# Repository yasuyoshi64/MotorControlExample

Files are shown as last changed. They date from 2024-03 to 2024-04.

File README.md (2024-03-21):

# sdkconfig
Serial flasher config

	Flash size				4MB

Partition Table

	Patition Table			Single factory app (large), no OTA

MotorControlExample

	LED GPIO number			5

SD card PIN configuration

	MOSI GPIO number		17
	MOSO GPIO number		19
	CLK GPIO number			18
	CS GPIO number			16
	SD card sw GPIO number	4

OLED(SSD1306) PIN configuration

	I2C SDA GPIO number		21
	I2C SCL GPIO number		22

MOTOR(BD65496) PIN configuration

	INA GPIO NUMBER			12
	INB GPIO NUMBER			13

HTTP Server

	WebSocket server support	TRUE

FAT Filesystem support

	Long filename support	Long filename buffer in heap
	OEM Code Page			Japanese (DBCS) (CP932)

Color settings

	Color depth.			1: 1 byte per pixel

Font usage

Enable built-in fonts

	Enable UNSCII 8 (Perfect monospace font)	TRUE

3rd Party Libraries

	QR code library			TRUE

# 機能

## SDカードの内容

### ./config

```
ssid=[Wi-Fi SSID]
pass=[Wi-Fi Password]
```

### ./document

ここにはWeb用のファイルを格納します。

## 使い方

* 「No file」と表示されている場合はSDカードを挿入します。
* 「Wi-Fi Connecting」はWi-Fi接続中です。
* Wi-Fi接続完了後はQRコードが表示されます。QRコードを読み込むとWebのURLが読み込まれ、documentのWebが表示されます。
* QRコードは30秒で消灯します。GPIO0のボタンを押下すると再度30秒表示されます。
* SDカードは電源ON中でも抜き差し可能です。

FA-130モーターは無負荷で70%くらいから回転を始めます。一度回転を始めれば40%くらいまで落としても回転します。
60% = 9000RPM ～　100% = 19000RPM

## 回路図

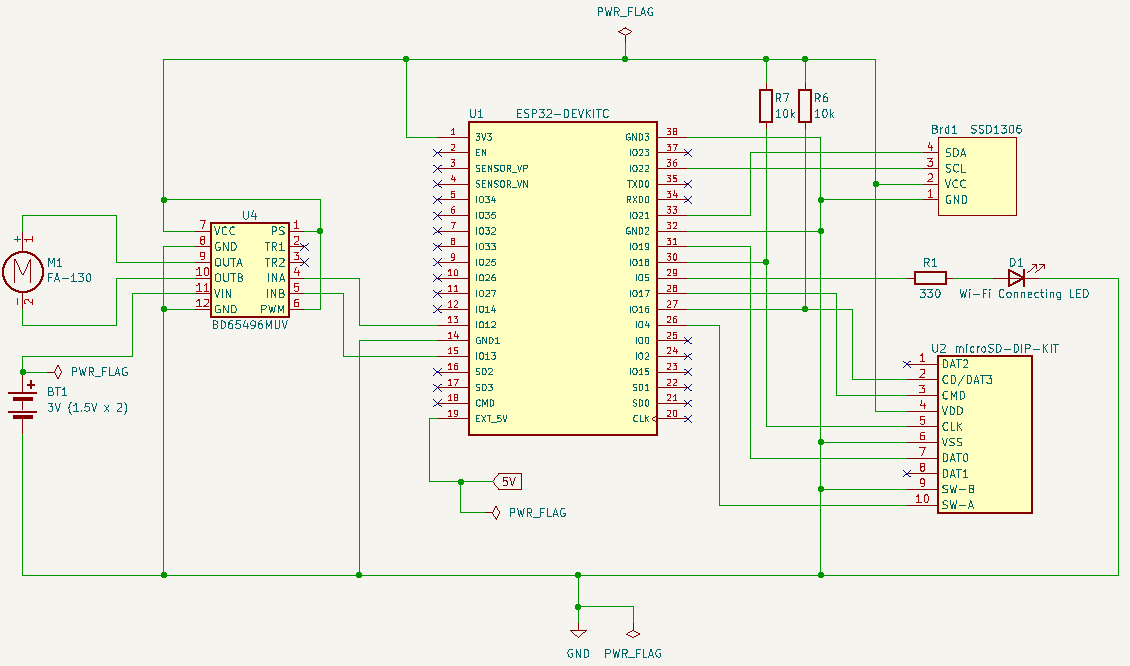
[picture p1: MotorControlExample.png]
回路図


## Web画面

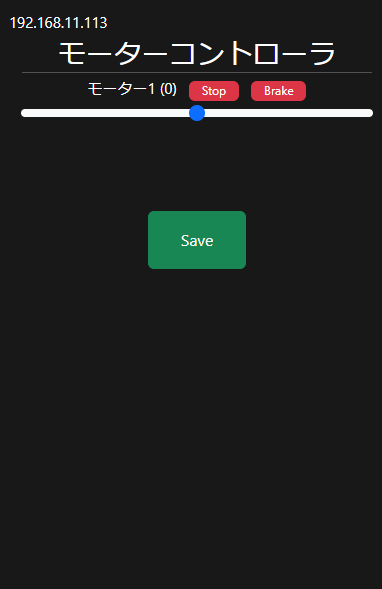
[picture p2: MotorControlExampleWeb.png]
Web画面


スライダーを動かすことでモーターを操作できます。
Saveボタンは何も機能しません。

# _Sample project_

(See the README.md file in the upper level 'examples' directory for more information about examples.)

This is the simplest buildable example. The example is used by command `idf.py create-project`
that copies the project to user specified path and set it's name. For more information follow the [docs page](https://docs.espressif.com/projects/esp-idf/en/latest/api-guides/build-system.html#start-a-new-project)

## How to use example
We encourage the users to use the example as a template for the new projects.
A recommended way is to follow the instructions on a [docs page](https://docs.espressif.com/projects/esp-idf/en/latest/api-guides/build-system.html#start-a-new-project).

## Example folder contents

The project **sample_project** contains one source file in C language [main.c](main/main.c). The file is located in folder [main](main).

ESP-IDF projects are built using CMake. The project build configuration is contained in `CMakeLists.txt`
files that provide set of directives and instructions describing the project's source files and targets
(executable, library, or both). 

Below is short explanation of remaining files in the project folder.

```
├── CMakeLists.txt
├── main
│   ├── CMakeLists.txt
│   └── main.c
└── README.md                  This is the file you are currently reading
```
Additionally, the sample project contains Makefile and component.mk files, used for the legacy Make based build system. 
They are not used or needed when building with CMake and idf.py.

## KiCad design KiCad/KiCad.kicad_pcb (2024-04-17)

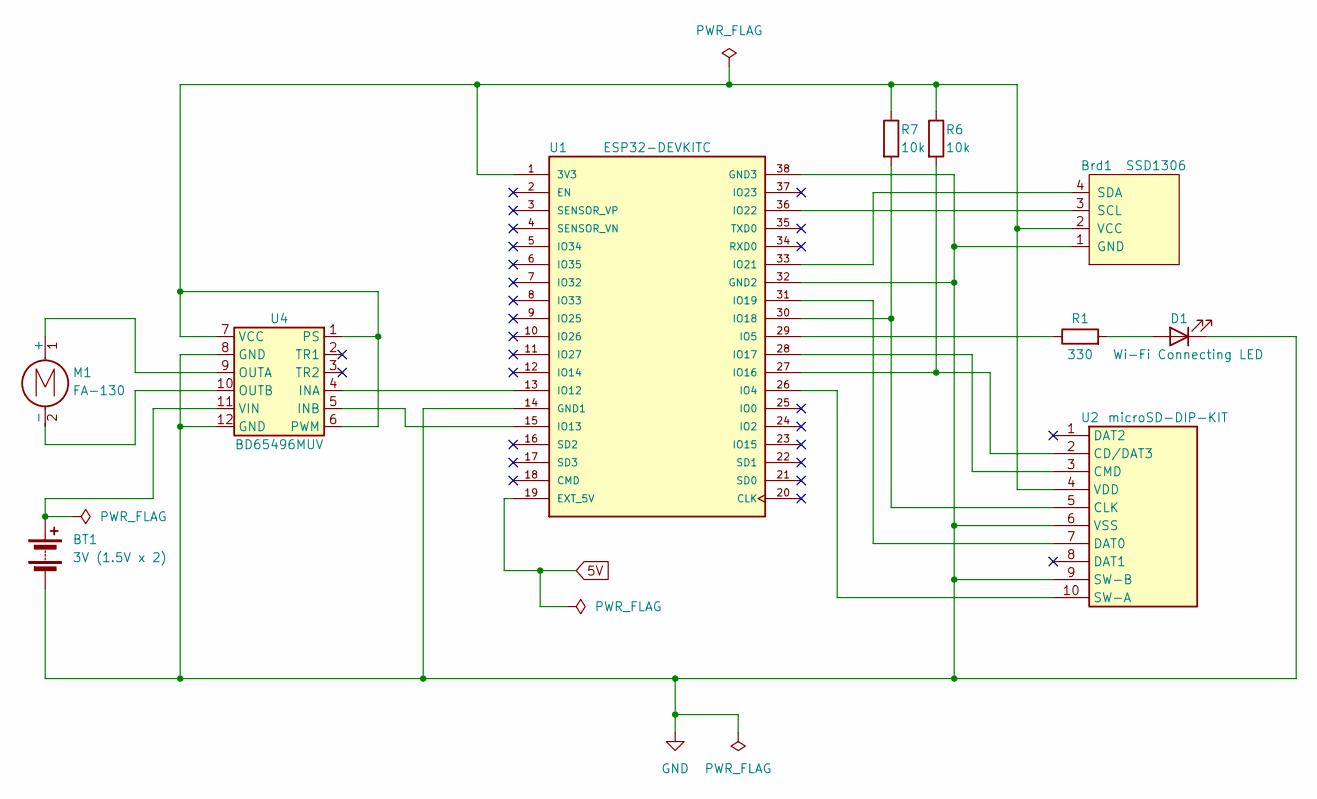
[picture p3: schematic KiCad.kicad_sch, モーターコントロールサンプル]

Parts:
BT1: 3V (1.5V x 2); PinHeader_1x02_P1.27mm_Vertical
Brd1: SSD1306; 128x64OLED
D1: Wi-Fi Connecting LED; LED_D5.0mm
M1: FA-130; PinHeader_1x02_P1.27mm_Vertical
R1: 330; R_Axial_DIN0204_L3.6mm_D1.6mm_P5.08mm_Horizontal
R6, R7: 10k; R_Axial_DIN0204_L3.6mm_D1.6mm_P5.08mm_Horizontal
U1: ESP32-DEVKITC; MODULE_ESP32-DEVKITC; PARTREV N/A
U2: microSD-DIP-KIT; microSD-DIP-Kit
U4: BD65496MUV

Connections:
5V: U1.19 (EXT_5V)
GND: BT1.2 (-), Brd1.1 (GND), D1.1 (K), U1.14 (GND1), U1.32 (GND2), U1.38 (GND3), U2.6 (VSS), U2.9 (SW-B), U4.8 (GND), U4.12 (GND)
unnamed: BT1.1 (+), U4.11 (VIN)
unnamed: Brd1.3 (SCL), U1.36 (IO22)
unnamed: Brd1.4 (SDA), U1.33 (IO21)
unnamed: Brd1.2 (VCC), R6.1, R7.1, U1.1 (3V3), U2.4 (VDD), U4.1 (PS), U4.6 (PWM), U4.7 (VCC)
unnamed: D1.2 (A), R1.2
unnamed: M1.1 (+), U4.9 (OUTA)
unnamed: M1.2 (-), U4.10 (OUTB)
unnamed: U1.26 (IO4), U2.10 (SW-A)
unnamed: R1.1, U1.29 (IO5)
unnamed: U1.13 (IO12), U4.4 (INA)
unnamed: U1.15 (IO13), U4.5 (INB)
unnamed: R6.2, U1.27 (IO16), U2.2 (CD/DAT3)
unnamed: U1.28 (IO17), U2.3 (CMD)
unnamed: R7.2, U1.30 (IO18), U2.5 (CLK)
unnamed: U1.31 (IO19), U2.7 (DAT0)

Board: 2 copper layers, 10 parts (0 on the bottom side), 16 nets, no tracks yet.

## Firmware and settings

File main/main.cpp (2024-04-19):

#include <stdio.h>
#include <sys/types.h>
#include <dirent.h>
#include <errno.h>
#include <string.h>
#include <iostream>
#include <map>
#include "freertos/FreeRTOS.h"
#include "freertos/task.h"
#include "freertos/queue.h"
#include "freertos/timers.h"
#include "nvs_flash.h"
#include "driver/gpio.h"
#include "esp_http_server.h"
#include "cJSON.h"
#include "esp_log.h"

#include "main.hpp"

#define TAG "Application"
#define ROOT "/mnt"

Application app;

// メッセージ種別 (メッセージキュー用)
enum class AppMessage {
    UpdateDisplay,      // ディスプレイに現在状態表示
    WIFIConnection,     // Wi-Fi接続
    WIFIDisconnection,  // Wi-Fi切断
    Quit                // 終了
};

Application::Application() {
    m_LedState = false;
    m_xHandle = NULL;
    m_xQueue = NULL;
    m_isWiFi = false;
    m_30sec_off = false;
}

// 初期化
void Application::init() {
    ESP_LOGI(TAG, "Init(S)");

    // LED初期化
    gpio_reset_pin((gpio_num_t)CONFIG_LED_PIN);
    gpio_set_direction((gpio_num_t)CONFIG_LED_PIN, GPIO_MODE_OUTPUT);
    led(0);

    // ボタン初期化(GPIO0)
    gpio_reset_pin((gpio_num_t)0);
    gpio_set_intr_type((gpio_num_t)0, GPIO_INTR_NEGEDGE);
    gpio_set_direction((gpio_num_t)0, GPIO_MODE_INPUT);
    gpio_pulldown_dis((gpio_num_t)0);
    gpio_pullup_en((gpio_num_t)0);
    gpio_install_isr_service(0);
    gpio_isr_handler_add((gpio_num_t)0, btn0HandlerFunc, (void*)this);

    // タスク作成
    xTaskCreate(Application::app_task, TAG, configMINIMAL_STACK_SIZE * 2, (void*)this, tskIDLE_PRIORITY, &m_xHandle);

    // メッセージキューの初期化
    m_xQueue = xQueueCreate(10, sizeof(AppMessage));

    // SDカード初期化
    m_sd_card.init(ROOT);
    m_sd_card.setMountCallback(mountFunc, this);

    // 保存データ初期化
    m_save_data.init(ROOT);

    // モーターコントローラー
    m_motor.init(0, (gpio_num_t)CONFIG_INA_PIN, (gpio_num_t)CONFIG_INB_PIN);

    // OLED(SSD1306)ディスプレイ初期化
    m_oled.init(dispInitCompFunc, this);

    // Wi-Fi初期化
    m_wifi.init(wifiConnectFunc, this);

    // Webサーバー初期化
    m_web.init();
    m_web.addHandler(HTTP_GET, "get_data", getData, this);
    m_web.addHandler(HTTP_POST, "set_data", setData, this);
    m_web.addHandler(HTTP_POST, "save", save, this);
    m_web.setWebSocketHandler(sebSocketFunc, this);

    ESP_LOGI(TAG, "Init(E)");
}

// タスク
void Application::app_task(void* arg) {
    Application* pThis = (Application*)arg;
    AppMessage msg;
    bool loop = true;
    while(loop) {
        // メッセージキュー読み取り
        if (pThis->m_xQueue != NULL && xQueueReceive(pThis->m_xQueue, (void*)&msg, portMAX_DELAY) == pdTRUE) {
            switch(msg) {
                case AppMessage::UpdateDisplay:     // ディスプレイに現在状態表示
                    pThis->updateDisplay();
                    break;
                case AppMessage::WIFIConnection:    // Wi-Fi接続
                    pThis->wifiConnection();
                    break;
                case AppMessage::WIFIDisconnection: // Wi-Fi切断
                    pThis->wifiDisconnection();
                    break;
                case AppMessage::Quit:              // 終了
                    loop = false;
                    break;
            }
        }
    }
    // 終了処理
    vTaskDelete(NULL);
}

// LED点灯制御
//  state   : 1=点灯, 0=消灯
void Application::led(int state) {
    m_LedState = state;
    gpio_set_level((gpio_num_t)CONFIG_LED_PIN, m_LedState);
}

// SDカードマウントコールバック
void Application::mountFunc(bool isMount, void* context) {
    ESP_LOGI(TAG, "SD Card mount : %d", isMount);
    Application* pThis = (Application*)context;
    AppMessage msg = AppMessage::UpdateDisplay;
    xQueueSend(pThis->m_xQueue, &msg, portMAX_DELAY);
    if (isMount && pThis->getConfig(ROOT)) {
        AppMessage msg = AppMessage::WIFIConnection;
        xQueueSend(pThis->m_xQueue, &msg, portMAX_DELAY);
    } else {
        AppMessage msg = AppMessage::WIFIDisconnection;
        xQueueSend(pThis->m_xQueue, &msg, portMAX_DELAY);
    }
    // 保存データ読み込み
    pThis->m_save_data.read();
}

// ファイル一覧コールバック
bool Application::fileFunc(bool isFile, const char* name, void* context) {
    ESP_LOGI(TAG, "%s : %s", isFile ? "File" : "Directory", name);
    return true;
}

// ディスプレイ初期化完了コールバック
void Application::dispInitCompFunc(void* context) {
    Application* pThis = (Application*)context;
    AppMessage msg = AppMessage::UpdateDisplay;
    xQueueSend(pThis->m_xQueue, &msg, portMAX_DELAY);
}

// Wi-Fi接続コールバック
void Application::wifiConnectFunc(bool isConnect, void* context) {
    Application* pThis = (Application*)context;
    if (isConnect) {
        pThis->m_30sec_off = pThis->m_isWiFi = true;
        const char* ipAddress = pThis->m_wifi.getIPAddress();
        ESP_LOGI(TAG, "IP Address: %s", ipAddress);
        pThis->led(0);
        pThis->m_web.start(ipAddress, ROOT);   // Webサーバー開始

        // 30秒後に画面を消灯するためにタイマ設定
        pThis->timer30secStart();

        // pThis->m_sd_card.fileLists("/document/", fileFunc, pThis);
    } else {
        ESP_LOGW(TAG, "wi-fi disconnect");
        pThis->m_30sec_off = pThis->m_isWiFi = false;
    }
    AppMessage msg = AppMessage::UpdateDisplay;
    xQueueSend(pThis->m_xQueue, &msg, portMAX_DELAY);
}

// 30秒タイマ開始
void Application::timer30secStart() {
    TimerHandle_t xTimer = xTimerCreate(
        "30SecTimer",
        pdMS_TO_TICKS(30000),
        pdFALSE,
        this,
        timer30secFunc
    );
    if (xTimer != NULL)
        xTimerStart(xTimer, 0);
}

// 30秒タイマ
void Application::timer30secFunc(TimerHandle_t xTimer) {
    Application* pThis = (Application*)pvTimerGetTimerID(xTimer);
    ESP_LOGI(TAG, "30s timer handler");
    pThis->m_30sec_off = false;
    AppMessage msg = AppMessage::UpdateDisplay;
    xQueueSend(pThis->m_xQueue, &msg, portMAX_DELAY);
}

// 基盤上のボタン押下ハンドラ (GPIO0)
void IRAM_ATTR Application::btn0HandlerFunc(void* context) {
    Application* pThis = (Application*)context;
    if (pThis->m_30sec_off == false) {
        pThis->m_30sec_off = true;
        pThis->timer30secStart();
        AppMessage msg = AppMessage::UpdateDisplay;
        xQueueSend(pThis->m_xQueue, &msg, portMAX_DELAY);
    }
}

// ディスプレイに現在状態表示
void Application::updateDisplay() {
    if (!m_oled.isInitialize())
        return;
    if (m_isWiFi) {
        if (m_30sec_off) {
            ESP_LOGI(TAG, "QRCode output");
            const char* ipAddress = m_wifi.getIPAddress();
            char url[256];
            sprintf(url, "http://%s/", ipAddress);
            m_oled.dispQRCode(url);
        } else {
            // 画面消灯
            m_oled.dispClear();
        }
    } else if (m_sd_card.isMount()) {
        m_oled.dispString("Wi-Fi Connecting");
        led(1);
    } else {
        m_oled.dispString("No File");
        led(0);
    }
}

// Wi-Fi接続
void Application::wifiConnection() {
    wifiDisconnection();
    if (m_configMap.find("ssid") == m_configMap.end() || m_configMap.find("pass") == m_configMap.end())
        return; // CONFIGファイルにssidまたはpassの設定がない
    const char* ssid = m_configMap["ssid"].c_str();
    const char* pass = m_configMap["pass"].c_str();
    m_wifi.connect(ssid, pass);
}

// Wi-Fi切断
void Application::wifiDisconnection() {
    m_web.stop();
    m_wifi.disconnect();
}

// WebAPI GET /API/get_data
// {
//   "ip_address": "192.168.0.1",
// }
void Application::getData(httpd_req_t *req, void* context) {
    ESP_LOGI(TAG, "getData");
    Application* pThis = (Application*)context;
    char resp[100];
    const char* ip_address = pThis->m_wifi.getIPAddress();
    ip_address = ip_address == NULL ? "" : ip_address;
    sprintf(resp, "{\"ip_address\": \"%s\" }", ip_address);
    ESP_LOGI(TAG, "%s", resp);
    httpd_resp_set_type(req, "application/json");
    httpd_resp_send(req, resp, strlen(resp));
}

// WebAPI POST /API/set_data
// {
//   "servo_trim": 5
// }
void Application::setData(httpd_req_t *req, void* context) {
    ESP_LOGI(TAG, "setData");
    Application* pThis = (Application*)context;
    int ret, remaining = req->content_len;
    char body[100];
    if (remaining >= sizeof(body)) {
        ESP_LOGE(TAG, "oversize request body");
        httpd_resp_send_500(req);
        return;
    }
    ret = httpd_req_recv(req, body, remaining);
    if (ret == HTTPD_SOCK_ERR_TIMEOUT) {
        ESP_LOGE(TAG, "timeout");
        httpd_resp_send_408(req);
        return;
    }
    body[ret] = '\0';
    ESP_LOGI(TAG, "body : %s", body);
    cJSON* json = cJSON_Parse(body);
    if (json == NULL) {
        ESP_LOGI(TAG, "json null");
        httpd_resp_send_500(req);
        return;
    }
    // cJSON* servo_trim = cJSON_GetObjectItemCaseSensitive(json, "servo_trim");
    // if (!cJSON_IsNumber(servo_trim)) {
    //     ESP_LOGI(TAG, "json format error");
    //     httpd_resp_send_500(req);
    //     return;
    // }
    // double trim = cJSON_GetNumberValue(servo_trim);
    // pThis->m_save_data.set("servo_trim", std::to_string(trim).c_str());
    cJSON_Delete(json);
    httpd_resp_send(req, NULL, 0);
}

// WebAPI POST /API/save
void Application::save(httpd_req_t *req, void* context) {
    ESP_LOGI(TAG, "save");
    Application* pThis = (Application*)context;
    pThis->m_save_data.save();
    httpd_resp_send(req, NULL, 0);
}

// WebSocketコールバック
char* Application::sebSocketFunc(const char* data, void* context) {
    Application* pThis = (Application*)context;
    ESP_LOGI(TAG, "data = %s", data);
    std::string str = data;
    int speed = 0;
    MotorDirection md = MotorDirection::Stop;
    if (str == "brake") {
        speed = 0;
        md = MotorDirection::Brake;
    } else {
        speed = std::stoi(str);
        if (speed == 0) {
            md = MotorDirection::Stop;
        } else if (speed > 0) {
            md = MotorDirection::Foward;
        } else if (speed < 0) {
            md = MotorDirection::Back;
            speed *= -1;
        }
    }
    pThis->m_motor.setDirection(md);
    pThis->m_motor.setSpeed(speed);
    return NULL;
}

extern "C" void app_main(void)
{
    nvs_flash_init();     // Flash初期化  (お約束のようなもの)

    app.init();
}

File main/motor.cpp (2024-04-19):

#include <cmath>
#include "motor.hpp"
#include "esp_log.h"

#define TAG "Motor"

#define MOTOR_PWM_RESOLUTION_HZ 1000000       // 1MHz, 1us per tick
#define MOTOR_PWM_PERIOD 100                // 100 tick, 100μs = 10kHzのPWM周期

// メッセージ種別 (メッセージキュー用)
enum class MotorMessage {
    Speed           // 速度
};

Motor::Motor() {
    clear();
}

void Motor::clear() {
    m_xHandle = NULL;
    m_xQueue = NULL;
    m_gpioINA = (gpio_num_t)0;
    m_gpioINB = (gpio_num_t)0;
    m_md = MotorDirection::Stop;
    m_timer = NULL;
    m_oper = NULL;
    m_comparator = NULL;
    m_generator = NULL;
    m_speed = 0;
}

void Motor::init(int groupID, gpio_num_t gpioINA, gpio_num_t gpioINB) {
    ESP_LOGI(TAG, "init(S)");

    m_groupID = groupID;
    m_gpioINA = gpioINA;
    m_gpioINB = gpioINB;

    // タスク作成
    xTaskCreate(Motor::task, TAG, configMINIMAL_STACK_SIZE * 2, (void*)this, 1, &m_xHandle);

    // メッセージキューの初期化
    m_xQueue = xQueueCreate(10, sizeof(MotorMessage));

    // PWM初期化
    ESP_LOGI(TAG, "init(1)");
    m_timer = NULL;
    mcpwm_timer_config_t timer_config = {
        .group_id = m_groupID,
        .clk_src = MCPWM_TIMER_CLK_SRC_DEFAULT,
        .resolution_hz = MOTOR_PWM_RESOLUTION_HZ,
        .count_mode = MCPWM_TIMER_COUNT_MODE_UP,
        .period_ticks = MOTOR_PWM_PERIOD,
    };
    esp_err_t ret = mcpwm_new_timer(&timer_config, &m_timer);
    if (ret != ESP_OK) {
        ESP_LOGE(TAG, "mcpwm_new_timer error %d", ret);
        return;
    }

    ESP_LOGI(TAG, "init(2)");
    m_oper = NULL;
    mcpwm_operator_config_t operator_config = {
        .group_id = m_groupID,
    };
    ret = mcpwm_new_operator(&operator_config, &m_oper);
    if (ret != ESP_OK) {
        ESP_LOGE(TAG, "mcpwm_new_operator error %d", ret);
        return;
    }
    ret = mcpwm_operator_connect_timer(m_oper, m_timer);
    if (ret != ESP_OK) {
        ESP_LOGE(TAG, "mcpwm_operator_connect_timer error %d", ret);
        return;
    }

    ESP_LOGI(TAG, "init(3)");
    m_comparator = NULL;
    mcpwm_comparator_config_t comparator_config {
        .flags = {
            .update_cmp_on_tez = true
        }
    };
    ret = mcpwm_new_comparator(m_oper, &comparator_config, &m_comparator);
    if (ret != ESP_OK) {
        ESP_LOGE(TAG, "mcpwm_new_comparator error %d", ret);
        return;
    }

    ESP_LOGI(TAG, "init(4)");
    m_generator = NULL;
    mcpwm_generator_config_t generator_config = {
        .gen_gpio_num = m_gpioINA,
    };
    ret = mcpwm_new_generator(m_oper, &generator_config, &m_generator);
    if (ret != ESP_OK) {
        ESP_LOGE(TAG, "mcpwm_new_generator error %d", ret);
        return;
    }
    if (m_generator == NULL) {
        ESP_LOGE(TAG, "mcpwm_new_generator error");
    }

    ESP_LOGI(TAG, "init(5) m_speed=%d", m_speed);
    ret = mcpwm_comparator_set_compare_value(m_comparator, (uint32_t)0);
    if (ret != ESP_OK) {
        ESP_LOGE(TAG, "mcpwm_comparator_set_compare_value error %d", ret);
        return;
    }

    ESP_LOGI(TAG, "init(6)");
    ret = mcpwm_generator_set_action_on_timer_event(m_generator,
            MCPWM_GEN_TIMER_EVENT_ACTION(MCPWM_TIMER_DIRECTION_UP, MCPWM_TIMER_EVENT_EMPTY, MCPWM_GEN_ACTION_HIGH));
    if (ret != ESP_OK) {
        ESP_LOGE(TAG, "mcpwm_generator_set_actions_on_timer_event error %d", ret);
        return;
    }
    ESP_LOGI(TAG, "init(7)");
    ret = mcpwm_generator_set_action_on_compare_event(m_generator,
            MCPWM_GEN_COMPARE_EVENT_ACTION(MCPWM_TIMER_DIRECTION_UP, m_comparator, MCPWM_GEN_ACTION_LOW));
    if (ret != ESP_OK) {
        ESP_LOGE(TAG, "mcpwm_generator_set_actions_on_compare_event error %d", ret);
        return;
    }
    
    ESP_LOGI(TAG, "init(8)");
    ret = mcpwm_timer_enable(m_timer);
    if (ret != ESP_OK) {
        ESP_LOGE(TAG, "mcpwm_timer_enable error %d", ret);
        return;
    }
    ESP_LOGI(TAG, "init(9)");
    ret = mcpwm_timer_start_stop(m_timer, MCPWM_TIMER_START_NO_STOP);
    if (ret != ESP_OK) {
        ESP_LOGE(TAG, "mcpwm_timer_start_stop error %d", ret);
        return;
    }

    // INB初期化
    ESP_LOGI(TAG, "init(10)");
    gpio_reset_pin(m_gpioINB);
    gpio_set_direction(m_gpioINB, GPIO_MODE_OUTPUT);

    setSpeed(m_speed);

    ESP_LOGI(TAG, "init(E)");
}

void Motor::setDirection(MotorDirection md) {
    m_md = md;
}

void Motor::setSpeed(int speed) {
    m_speed = speed;    
    // 新しいメッセージキューをポスト
    MotorMessage msg = MotorMessage::Speed;
    xQueueSend(m_xQueue, &msg, portMAX_DELAY);
}

void Motor::task(void* arg) {
    Motor* pThis = (Motor*)arg;
    MotorMessage msg;
    bool loop = true;
    while(loop) {
        // メツセージキュー読み取り
        if (pThis->m_xQueue != NULL && xQueueReceive(pThis->m_xQueue, (void*)&msg, portMAX_DELAY) == pdTRUE) {
            switch(msg) {
                case MotorMessage::Speed:       // 速度
                    pThis->speed();
                    break;
            }
        }
    }
}

void Motor::speed() {
    esp_err_t ret;
    int speed1 = 0;
    int speed2 = 0;
    switch(m_md) {
        case MotorDirection::Foward:    // 前進
            speed1 = m_speed;
            speed2 = 0;
            break;
        case MotorDirection::Back:      // 後退
            speed1 = m_speed;
            speed2 = 1;
            break;
        case MotorDirection::Stop:      // 停止
            speed1 = 0;
            speed2 = 0;
            break;
        case MotorDirection::Brake:     // ブレーキ
            speed1 = 0;
            speed2 = 0;
            break;
    }
    gpio_set_level(m_gpioINB, speed2);
    if ((ret = mcpwm_comparator_set_compare_value(m_comparator, (uint32_t)speed1)) != ESP_OK) {
        gpio_set_level(m_gpioINB, 0);
        ESP_LOGE(TAG, "mcpwm_comparator_set_compare_value error %d", ret);
    }
}

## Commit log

2024-03-11 初期コミット
    [KiCad.kicad_pcb, KiCad.kicad_sch]
2024-03-16 モーターコントロールを追加
    [KiCad.kicad_sch]
2024-03-16 PWMピンの意味を勘違いしてて修正
2024-03-21 画像追加
2024-03-21 説明追加
2024-04-17 モーター2個に増量
    [KiCad.kicad_sch]
2024-04-17 KiCadの回路図追加
    [KiCad.kicad_pcb, KiCad.kicad_sch]
2024-04-17 ミスった
    [KiCad.kicad_pcb, KiCad.kicad_sch]
2024-04-18 BD65496MUVのPWMをLOWへ
    [KiCad.kicad_sch]
2024-04-19 BD65496MUVをEN/INモードで動作するように変更
    [KiCad.kicad_sch]
